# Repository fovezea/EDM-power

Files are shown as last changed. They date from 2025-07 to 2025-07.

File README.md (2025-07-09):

# EDM Power Control System

A comprehensive ESP32-based EDM (Electrical Discharge Machining) power supply and control system with real-time web interface, PID control, and persistent settings management.

## 🎯 **Project Goals**

- **Real-time EDM Control**: Precise electrode positioning with PID feedback
- **Web Interface**: Modern responsive web UI for monitoring and control
- **Persistent Settings**: NVS-based settings storage with web configuration
- **Safety Features**: Limit switch protection and emergency stops
- **Modular Design**: Clean separation of concerns for maintainability

### **EDM Philosophy & Approach**

EDM machines, due to the spark (plasma) not being fully understood and the lack of a mathematical model that fits the way we try to simplify the equations, are still esoteric in nature and there is still a lot of empirical approach. Combined with the variety of materials and electrodes, this creates a complex situation.

As far as I understand, there is not a single type of power source in an industrial machine, but rather a combination of several sources depending on the operation. The target is to have flexibility to control the same hardware to do as much as possible.

There is a lot of documentation and publications out there, but there is still a gap between implementation and theoretical approach.

## ✨ **Current Features**

### 🔧 **Core EDM Functionality**
- **Stepper Motor Control**: Smooth acceleration/deceleration with RMT peripheral
- **PID Control Loop**: Configurable proportional, integral, and derivative gains
- **Gap Voltage Monitoring**: Real-time ADC sampling with configurable blanking delay
- **PWM Power Generation**: Half-bridge IGBT control with dead time protection
- **Safety Interlocks**: Limit switch protection and emergency stop functionality

### 🌐 **Web Interface & Connectivity**
- **WiFi Station Mode**: Automatic connection with retry logic
- **Real-time Web UI**: Modern responsive interface accessible via browser
- **WebSocket Communication**: Live status updates and command control
- **Cross-platform**: Works on desktop, tablet, and mobile devices

### ⚙️ **Settings Management**
- **Persistent Storage**: NVS-based settings that survive power cycles
- **Web Configuration**: Real-time parameter adjustment via web interface
- **Default Values**: Automatic fallback to sensible defaults
- **Settings Reset**: One-click restore to factory defaults

### 📊 **Configurable Parameters**
- **PWM Duty Cycle**: 1-99% with real-time adjustment
- **ADC Blanking Delay**: 10-200 ticks for noise filtering
- **PID Parameters**: 
  - Kp (Proportional): 0.000-1.000
  - Ki (Integral): 0.000-1.000  
  - Kd (Derivative): 0.000-1.000
  - Setpoint: 0-4095 ADC value
- **Speed Settings**: Jog and cut speeds in mm/s

## 🚀 **Getting Started**

### **Prerequisites**
- ESP-IDF v5.4.1 or later
- ESP32 development board
- DRV8825 stepper motor driver
- 4-wire stepper motor
- Half-bridge IGBT module
- Limit switch and control buttons

### **Hardware Connections**

```
+---------------------------+             +--------------------+      +--------------+
|          ESP32 Board      |             |       DRV8825      |      |    4-wire    |
|                       GND +-------------+ GND                |      |     Step     |
|                           |             |                    |      |     Motor    |
|                       3V3 +-------------+ VDD             A+ +------+ A+           |
|                           |             |                    |      |              |
|       GPIO 2 (DIR)        +------------>+ DIR             A- +------+ A-           |
|                           |             |                    |      |              |
|       GPIO 4 (STEP)       +------------>+ STEP            B- +------+ B-           |
|                           |             |                    |      |              |
|                           |      3V3----+ nSLEEP          B+ +------+ B+           |
|                           |             |                    |      +--------------+
|                           |      3V3----+ nRST            VM +-------------------+
|                           |             |                    |                   |
|                           |  3V3|GND----+ M2             GND +----------+        |
|                           |             |                    |          |        |
|                           |  3V3|GND----+ M1                 |          |        |
|                           |             |                    |          |        |
|                           |  3V3|GND----+ M0                 |      +---+--------+-----+
|                           |             |                    |      |  GND     +12V    |
|       GPIO 0 (ENABLE)     +------------>+ nEN                |      |   POWER SUPPLY   |
+---------------------------+             +--------------------+      +------------------+

PWM Outputs:
- GPIO 16 (PWM0A) -> IGBT High Side
- GPIO 17 (PWM0B) -> IGBT Low Side
- GPIO 18 (CAP)   -> External Signal Capture

Control Inputs:
- GPIO 12 (JOG_UP)     -> Jog Up Button
- GPIO 13 (JOG_DOWN)   -> Jog Down Button  
- GPIO 14 (LIMIT)      -> Limit Switch
- GPIO 15 (START_CUT)  -> Start/Stop Button

ADC Input:
- GPIO 6 (ADC_CH6)     -> Gap Voltage Sensing
```

### **Build and Flash**

1. **Configure WiFi** (optional):
   ```bash
   idf.py menuconfig
   # Navigate to: Component config -> WiFi Configuration
   # Set your WiFi credentials
   ```

2. **Build and flash**:
   ```bash
   idf.py build
   idf.py -p [PORT] flash monitor
   ```

3. **Access Web Interface**:
   - Connect to the ESP32's WiFi network (if in AP mode)
   - Or connect to your WiFi and note the IP address from serial output
   - Open browser and navigate to: `http://[ESP32_IP_ADDRESS]`

## 📁 **Project Structure**

```
main/
├── main.c                 # Core application logic and task management
├── MCPWM_task.c          # PWM generation and PID control loop
├── ADC.c                 # ADC sampling and gap voltage capture
├── stepper_motor_encoder.c # RMT-based stepper motor control
├── wifi_connect.c        # WiFi station mode with auto-reconnect
├── web_server.c          # HTTP server and WebSocket communication
├── settings.c            # NVS-based persistent settings management
├── web_server.h          # Web interface definitions
├── wifi_connect.h        # WiFi connection interface
└── settings.h            # Settings management interface
```

## 🎛️ **Web Interface Features**

### **Real-time Monitoring**
- **Gap Voltage**: Live ADC readings with voltage conversion
- **PWM Duty Cycle**: Current duty cycle percentage
- **System Status**: Cutting state, limit switch, WiFi connection
- **Motor Position**: Current step position and speeds
- **PID Parameters**: Current Kp, Ki, Kd, and setpoint values

### **Control Panel**
- **EDM Control**: Start/Stop cutting operations
- **Manual Jogging**: Up/Down movement with safety limits
- **Home Position**: Return to reference position
- **Settings Reset**: Restore factory defaults

### **Parameter Configuration**
- **Duty Cycle Slider**: 1-99% PWM control
- **ADC Blanking Delay**: 10-200 ticks for noise filtering
- **PID Tuning**: Real-time adjustment of control parameters
- **Setpoint Control**: Target ADC value for gap control

## 🔧 **Technical Details**

### **RMT-Based Stepper Control**
One RMT TX channel can use different encoders in sequence, which is useful to generate waveforms that have multiple stages.

To smoothly drive a stepper motor, there are three phases: **Acceleration**, **Uniform**, and **Deceleration**. The code implements two encoders so that the RMT channel can generate waveforms with different characteristics:

* `curve_encoder` encodes the **Acceleration** and **Deceleration** phases
* `uniform_encoder` encodes the **Uniform** phase

### **PID Control Loop**
The system uses a PID controller to maintain optimal gap voltage:
- **Proportional (Kp)**: Responds to current error
- **Integral (Ki)**: Eliminates steady-state error
- **Derivative (Kd)**: Reduces overshoot and oscillations
- **Setpoint**: Target ADC value for gap control

### **Control Logic & Safety Features**

The main control loop implements comprehensive safety and operational logic:

- **Jogging Control**: Manual movement only allowed if limit switch is ON (not triggered)
- **EDM Cutting**: Only runs if not jogging, limit switch is ON, and start button is ON
- **Safety Inhibition**: If limit switch is OFF, all movement is inhibited (including jogging and EDM control)
- **Range Validation**: All parameters validated before application
- **Fault Logging**: Comprehensive error reporting

The loop now fully supports the new safety and control logic with clear separation of jog and cut operations.

### **Safety Features**
- **Limit Switch Protection**: Inhibits all movement when triggered
- **Emergency Stop**: Immediate halt of all operations
- **Range Validation**: All parameters validated before application
- **Fault Logging**: Comprehensive error reporting

### **Performance Characteristics**
- **Update Rate**: 50Hz PID control loop
- **ADC Resolution**: 12-bit (0-4095)
- **PWM Frequency**: 20kHz with configurable duty cycle
- **Stepper Resolution**: 200 steps/revolution
- **WebSocket Latency**: <100ms for real-time control

## 🛠️ **Configuration**

### **WiFi Setup**
Edit `main/wifi_connect.c` to configure your WiFi credentials:
```c
#define WIFI_SSID "your_wifi_ssid"
#define WIFI_PASS "your_wifi_password"
```

### **GPIO Configuration**
Modify GPIO assignments in `main/main.c`:
```c
#define STEP_MOTOR_GPIO_EN       0
#define STEP_MOTOR_GPIO_DIR      2
#define STEP_MOTOR_GPIO_STEP     4
#define JOG_UP_GPIO   12
#define JOG_DOWN_GPIO 13
#define LIMIT_SWITCH_GPIO 14
#define START_CUT_GPIO    15
```

### **Default Settings**
Adjust default values in `main/settings.h`:
```c
#define DEFAULT_DUTY_PERCENT 40
#define DEFAULT_ADC_BLANKING_DELAY 1
#define DEFAULT_PID_KP 0.05f
#define DEFAULT_PID_KI 0.01f
#define DEFAULT_PID_KD 0.0f
#define DEFAULT_PID_SETPOINT 1500
```

## 📈 **Future Enhancements**

- **External ADC Support**: Higher precision voltage measurement
- **Multi-axis Control**: Support for X, Y, Z positioning
- **G-code Interpreter**: CNC-style programming interface
- **Data Logging**: Historical performance tracking
- **Advanced PID Tuning**: Auto-tuning algorithms
- **Material Database**: Pre-configured settings for different materials

## 🤝 **Contributing**

This project is actively developed for EDM applications. Contributions are welcome for:
- Hardware improvements
- Control algorithm enhancements
- Web interface features
- Documentation updates

## 📄 **License**

This project is open source. See LICENSE file for details.

## 📸 **Project Hardware Setup**

Below is a photo of the current hardware setup:

Project Hardware Setup

---

**Note**: This hardware schematic is writen in Kicad 9 but so far is just  power stage control without the reset of the generator. It will be added soon
**Note**: This system is designed for educational and experimental use. Always follow proper safety procedures when working with high-voltage EDM systems.

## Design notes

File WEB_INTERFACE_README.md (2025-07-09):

# EDM Power Control - Web Interface

## 🚀 Overview

Your EDM system now includes a complete web-based control interface that allows you to monitor and control your EDM machine remotely via WiFi.

## 📋 Features

### Real-time Monitoring
- **PWM Duty Cycle** - Live display and control (1-99%)
- **Gap Voltage** - Real-time ADC readings with voltage conversion
- **System Status** - Cutting status, limit switch, WiFi connection
- **Speed Parameters** - Jog speed, cut speed, stepper position
- **Uptime** - System running time

### Remote Control
- **Start/Stop EDM Cutting** - Remote control of cutting process
- **Jog Controls** - Up/down movement commands
- **Home Position** - Return to reference position
- **Duty Cycle Adjustment** - Real-time PWM control via slider

### Live Charting
- **Gap Voltage Chart** - Real-time plotting of gap voltage over time
- **Auto-scaling** - Adapts to voltage range
- **Data History** - Last 50 data points displayed

## 🔧 Setup Instructions

### 1. Configure WiFi
Edit `main/wifi_connect.h` and set your WiFi credentials:
```c
#define WIFI_SSID "YOUR_WIFI_SSID"
#define WIFI_PASS "YOUR_WIFI_PASSWORD"
```

### 2. Build and Flash
```bash
idf.py build
idf.py flash monitor
```

### 3. Access the Web Interface
1. Connect your device to the same WiFi network as your ESP32
2. Look for the ESP32's IP address in the serial monitor output
3. Open your web browser and navigate to: `http://[ESP32_IP_ADDRESS]`

## 🎮 How to Use

### Web Interface Controls

#### **Status Cards**
- **PWM Duty Cycle**: Shows current duty cycle and provides a slider for adjustment
- **Gap Voltage**: Displays real-time gap voltage in millivolts and raw ADC value
- **System Status**: Shows cutting status, limit switch state, and WiFi connection
- **Speeds**: Displays jog speed, cut speed, and current stepper position

#### **Control Panel**
- **Start EDM Cut**: Begin the EDM cutting process
- **Stop EDM Cut**: Stop the EDM cutting process
- **Jog Up**: Move electrode up
- **Jog Down**: Move electrode down
- **Home Position**: Return to home position

#### **Real-time Chart**
- **Gap Voltage Chart**: Live plotting of gap voltage over time
- **Auto-scaling**: Automatically adjusts to show the full voltage range
- **Data History**: Maintains the last 50 data points

### Connection Status
- **Green**: Connected to ESP32 via WebSocket
- **Red**: Disconnected (will auto-reconnect)

## 🔌 Technical Details

### WebSocket Communication
- **Real-time Updates**: 1-second refresh rate
- **Bidirectional**: Commands from web to ESP32, status from ESP32 to web
- **Multiple Clients**: Support for up to 4 simultaneous connections
- **Auto-reconnection**: Client automatically reconnects if connection lost

### Integration with EDM System
- **Command Queue**: Thread-safe communication between web and main tasks
- **Status Synchronization**: Real-time updates from existing EDM code
- **Error Handling**: Graceful fallback if WiFi/web server fails
- **ESP-IDF v5.4.1 Compatible**: Uses latest APIs

## 📱 Mobile Support
The web interface is fully responsive and works on:
- Desktop computers
- Tablets
- Smartphones

## 🛠️ Troubleshooting

### WiFi Connection Issues
1. Check WiFi credentials in `wifi_connect.h`
2. Ensure ESP32 is within WiFi range
3. Check serial monitor for connection status

### Web Interface Not Loading
1. Verify ESP32 IP address in serial monitor
2. Check if ESP32 and device are on same network
3. Try refreshing the browser page

### Commands Not Working
1. Check WebSocket connection status (should be green)
2. Verify ESP32 is not in a critical state (limit switch triggered)
3. Check serial monitor for error messages

## 🔒 Security Notes
- The web interface is designed for local network use
- No authentication is implemented (add if needed for production)
- Consider using HTTPS for production environments

## 📊 Performance
- **Update Rate**: 1 second for status updates
- **Chart Data**: 50 data points maintained
- **Memory Usage**: ~8KB for web server task
- **CPU Usage**: Minimal impact on EDM performance

## 🎯 Next Steps
Consider adding these features:
- **User Authentication**: Login system for security
- **Data Logging**: Save cutting data to SD card
- **Email Alerts**: Notifications for system events
- **Advanced Charts**: Multiple parameter plotting
- **Recipe Management**: Save and load cutting parameters

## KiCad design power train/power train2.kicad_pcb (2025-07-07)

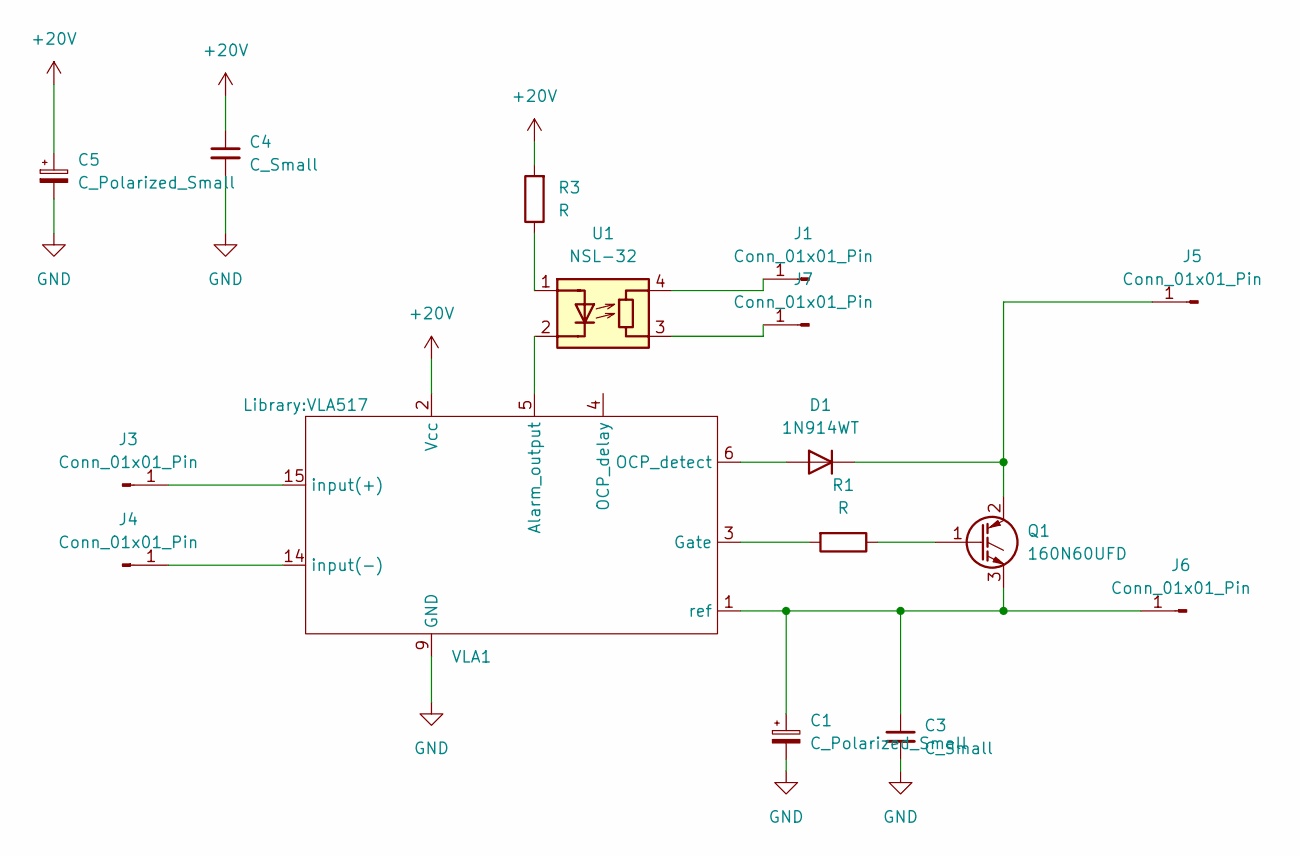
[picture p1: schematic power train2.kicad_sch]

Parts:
C1, C5: C_Polarized_Small; CP_Radial_D8.0mm_P3.50mm
C3, C4: C_Small; C_Axial_L5.1mm_D3.1mm_P7.50mm_Horizontal
D1: 1N914WT; D_SOD-523
J1, J3, J4, J5, J6, J7: Conn_01x01_Pin; TestPoint_THTPad_1.0x1.0mm_Drill0.5mm
Q1: 160N60UFD; TO-264-3_Vertical
R1, R3: R; R_Axial_DIN0309_L9.0mm_D3.2mm_P12.70mm_Horizontal
U1: NSL-32; Luna_NSL-32
VLA1: VLA517

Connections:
+20V: C4.1, C5.1, R3.2, VLA1.2 (Vcc)
GND: C1.2, C3.2, C4.2, C5.2, VLA1.9 (GND)
unnamed: D1.2 (A), VLA1.6 (OCP_detect)
unnamed: D1.1 (K), J5.1, Q1.2 (C)
unnamed: J1.1, U1.4 (R)
unnamed: J3.1, VLA1.15 (input(+))
unnamed: J4.1, VLA1.14 (input(-))
unnamed: C1.1, C3.1, J6.1, Q1.3 (E), VLA1.1 (ref)
unnamed: J7.1, U1.3 (R)
unnamed: Q1.1 (G), R1.1
unnamed: R3.1, U1.1 (A)
unnamed: U1.2 (K), VLA1.5 (Alarm_output)
unnamed: R1.2, VLA1.3 (Gate)

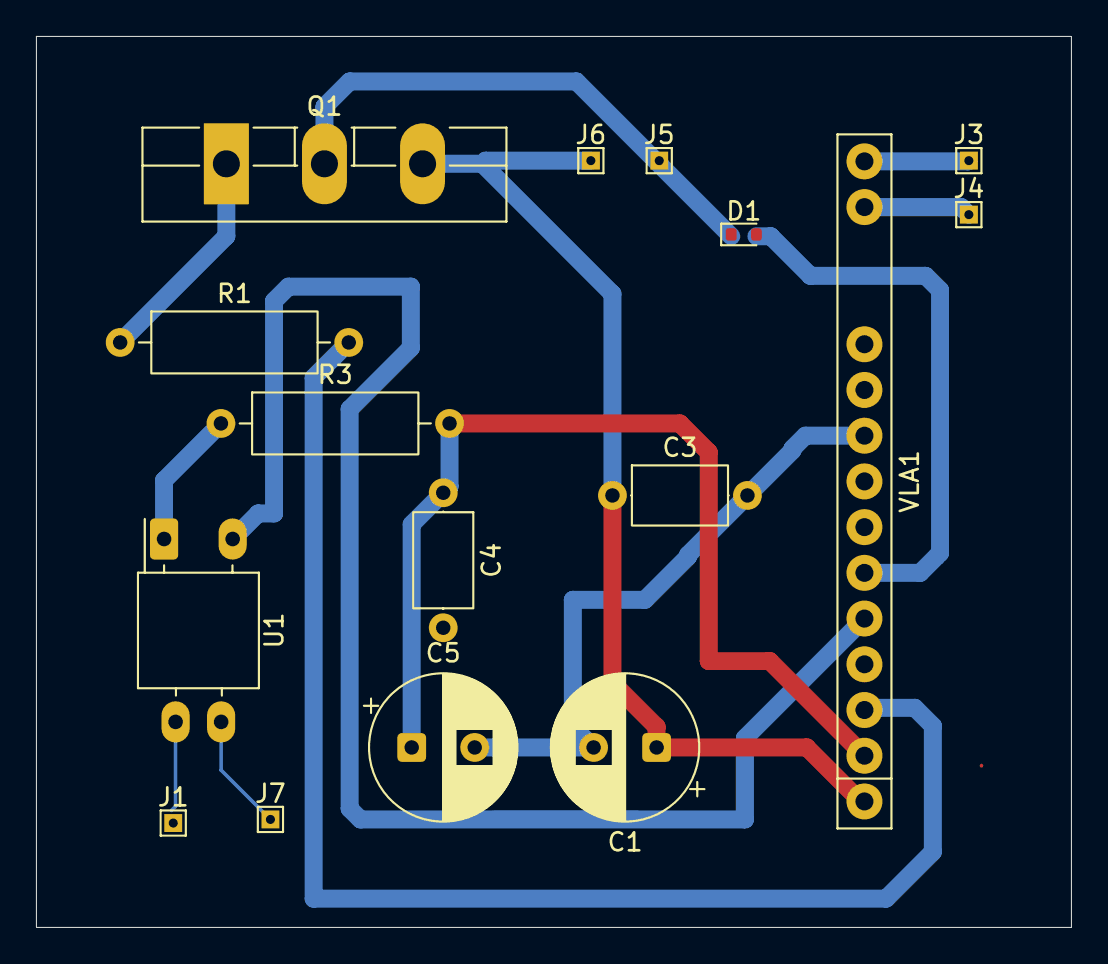
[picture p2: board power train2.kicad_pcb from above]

Board: 2 copper layers, 57.5 x 49.5 mm, 16 parts (0 on the bottom side), 13 nets.

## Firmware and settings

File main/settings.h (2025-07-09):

/*
 * Settings Management for EDM Power Project
 * Uses NVS (Non-Volatile Storage) for persistent settings
 */

#pragma once

#include "esp_err.h"
#include "nvs_flash.h"
#include "nvs.h"

#ifdef __cplusplus
extern "C" {
#endif

// Settings structure
typedef struct {
    int duty_percent;           // PWM duty cycle (1-99)
    int adc_blanking_delay;     // ADC lead edge blanking delay (10-200 ticks)
    float jog_speed;            // Jog speed in mm/s
    float cut_speed;            // Cut speed in mm/s
    // PID control parameters
    float pid_kp;               // Proportional gain
    float pid_ki;               // Integral gain
    float pid_kd;               // Derivative gain
    int pid_setpoint;           // Target ADC value
    bool pid_control_enabled;   // Whether PID control is enabled
    // Add more settings as needed
} edm_settings_t;

// Function declarations
esp_err_t settings_init(void);
esp_err_t settings_load(edm_settings_t *settings);
esp_err_t settings_save(const edm_settings_t *settings);
esp_err_t settings_reset_to_defaults(void);
void settings_deinit(void);

// Default settings
#define DEFAULT_DUTY_PERCENT 40
#define DEFAULT_ADC_BLANKING_DELAY 10
#define DEFAULT_JOG_SPEED 1.0f
#define DEFAULT_CUT_SPEED 0.1f
// PID default values
#define DEFAULT_PID_KP 0.05f
#define DEFAULT_PID_KI 0.01f
#define DEFAULT_PID_KD 0.0f
#define DEFAULT_PID_SETPOINT 1500
#define DEFAULT_PID_CONTROL_ENABLED false

#ifdef __cplusplus
}
#endif 

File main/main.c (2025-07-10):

/*
 * SPDX-FileCopyrightText: 2021-2022 Espressif Systems (Shanghai) CO LTD
 *
 * SPDX-License-Identifier: Unlicense OR CC0-1.0
 */

#include "freertos/FreeRTOS.h"
#include "freertos/task.h"
#include "driver/rmt_tx.h"
#include "driver/gpio.h"
#include "esp_log.h"
#include "stepper_motor_encoder.h"
#include "freertos/semphr.h"
#include "nvs_flash.h"

#include "esp_adc/adc_cali.h"
#include "esp_adc/adc_cali_scheme.h"
#include "esp_adc/adc_oneshot.h"

// Web server and WiFi includes
#include "wifi_connect.h"
#include "web_server.h"
#include "settings.h"
#include "freertos/queue.h"
#include <string.h>

///////////////////////////////Change the following configurations according to your board//////////////////////////////
#define STEP_MOTOR_GPIO_EN       0
#define STEP_MOTOR_GPIO_DIR      2
#define STEP_MOTOR_GPIO_STEP     4
#define STEP_MOTOR_ENABLE_LEVEL  0 // DRV8825 is enabled on low level
#define STEP_MOTOR_SPIN_DIR_CLOCKWISE 0
#define STEP_MOTOR_SPIN_DIR_COUNTERCLOCKWISE !STEP_MOTOR_SPIN_DIR_CLOCKWISE
#define HYSTERESIS_WIDTH 100 // ADC value dead zone width
//buttons for jogging
#define JOG_UP_GPIO   12  // Choose your GPIO numbers
#define JOG_DOWN_GPIO 13
#define LIMIT_SWITCH_GPIO 14
#define START_CUT_GPIO    15

#define STEP_MOTOR_RESOLUTION_HZ 1000000 // 1MHz resolution

// Speed and leadscrew pitch settings
double jog_speed_mm_per_s = 1; // Speed in mm/s, can be set from elsewhere
double cut_speed_mm_per_s = 0.1; // Speed in mm/s, can be set from elsewhere
double leadscrew_pitch_mm = 4.0; // Leadscrew pitch in mm/rev
double steps_per_rev = 2000; // Pulses per revolution (e.g., 200 for 1.8 degree stepper)

static const char *TAG = "main";

#include "freertos/queue.h"
QueueHandle_t pwm_adc_queue = NULL;

// Only extern variables that are defined in other files and actually used in main.c
extern volatile uint32_t last_capture_ticks;
extern volatile int adc_value_on_capture;
extern SemaphoreHandle_t capture_semaphore;

// Extern declaration for adc_on_capture_task (defined in ADC.c)
extern void adc_on_capture_task(void *pvParameters);
extern void mcpwm_halfbridge_task(void *pvParameters);
extern void adc_oneshot_init(void); // Add extern for ADC init

// Web server integration variables
static volatile bool edm_cutting_enabled = false;
static volatile bool jog_up_requested = false;
static volatile bool jog_down_requested = false;
static volatile bool home_position_requested = false;
static volatile bool web_control_active = false; // Default: physical buttons in control
QueueHandle_t command_queue = NULL;

// Command structure for web interface
typedef struct {
    char command[32];
    int value;
} web_command_t;

// Web server task function declaration
void web_server_task(void *pvParameters);
extern esp_err_t web_server_init(void);

// Local static/global variables (defined in this file and actually used)
static rmt_channel_handle_t motor_chan;
static rmt_encoder_handle_t accel_motor_encoder;
static rmt_encoder_handle_t uniform_motor_encoder;
static rmt_encoder_handle_t decel_motor_encoder;
static rmt_encoder_handle_t cut_motor_encoder = NULL;
// Pre-configured cut encoders for different speeds
static rmt_encoder_handle_t cut_encoder_slow = NULL;    // 0.01-0.1 mm/s
static rmt_encoder_handle_t cut_encoder_medium = NULL;  // 0.1-0.5 mm/s  
static rmt_encoder_handle_t cut_encoder_fast = NULL;    // 0.5-1.0 mm/s

// Web server integration functions
bool get_edm_cutting_status(void) {
    return edm_cutting_enabled;
}

bool get_jog_up_requested(void) {
    bool requested = jog_up_requested;
    jog_up_requested = false; // Clear the request
    return requested;
}

bool get_jog_down_requested(void) {
    bool requested = jog_down_requested;
    jog_down_requested = false; // Clear the request
    return requested;
}

bool get_home_position_requested(void) {
    bool requested = home_position_requested;
    home_position_requested = false; // Clear the request
    return requested;
}

bool get_web_control_active(void) {
    return web_control_active;
}

void set_web_control_active(bool active) {
    if (active && !web_control_active) {
        // When switching to web control, inherit the current physical cutting state
        int physical_start_cut = gpio_get_level(START_CUT_GPIO);
        edm_cutting_enabled = (physical_start_cut == 1);
        ESP_LOGI(TAG, "Taking web control - inherited cutting state: %s", 
                 edm_cutting_enabled ? "CUTTING" : "STOPPED");
    }
    
    web_control_active = active;
    ESP_LOGI(TAG, "Control switched to: %s", active ? "WEB" : "PHYSICAL");
}

// Function to select appropriate pre-configured encoder based on cut speed
void update_cut_motor_encoder(void) {
    ESP_LOGI(TAG, "=== Selecting cut motor encoder ===");
    ESP_LOGI(TAG, "Current cut_speed_mm_per_s: %.3f", cut_speed_mm_per_s);
    
    rmt_encoder_handle_t old_encoder = cut_motor_encoder;
    
    // Select encoder based on speed range
    if (cut_speed_mm_per_s <= 0.1) {
        cut_motor_encoder = cut_encoder_slow;
        ESP_LOGI(TAG, "Selected SLOW encoder for %.3f mm/s", cut_speed_mm_per_s);
    } else if (cut_speed_mm_per_s <= 0.5) {
        cut_motor_encoder = cut_encoder_medium;
        ESP_LOGI(TAG, "Selected MEDIUM encoder for %.3f mm/s", cut_speed_mm_per_s);
    } else {
        cut_motor_encoder = cut_encoder_fast;
        ESP_LOGI(TAG, "Selected FAST encoder for %.3f mm/s", cut_speed_mm_per_s);
    }
    
    if (cut_motor_encoder == NULL) {
        ESP_LOGE(TAG, "✗ Selected encoder is NULL! Falling back to uniform encoder");
        cut_motor_encoder = uniform_motor_encoder;
    } else {
        ESP_LOGI(TAG, "✓ Cut encoder selected: old=%p, new=%p", old_encoder, cut_motor_encoder);
    }
    ESP_LOGI(TAG, "=== Encoder selection complete ===");
}

// Web server integration task
void web_integration_task(void *pvParameters)
{
    ESP_LOGI(TAG, "Web integration task started");
    
    // Create command queue
    command_queue = xQueueCreate(10, sizeof(web_command_t));
    
    // Initialize WiFi first
    esp_err_t wifi_ret = wifi_init_sta();
    if (wifi_ret != ESP_OK) {
        ESP_LOGE(TAG, "Failed to connect to WiFi, web interface will not be available");
    } else {
        ESP_LOGI(TAG, "WiFi connected successfully");
        
        // Wait a bit for WiFi to stabilize
        vTaskDelay(pdMS_TO_TICKS(2000));
        
        // Initialize web server
        esp_err_t web_ret = web_server_start();
        if (web_ret != ESP_OK) {
            ESP_LOGE(TAG, "Failed to start web server, retrying...");
            // Wait and retry once
            vTaskDelay(pdMS_TO_TICKS(5000));
            web_ret = web_server_start();
            if (web_ret != ESP_OK) {
                ESP_LOGE(TAG, "Web server start failed after retry, continuing without web interface");
            } else {
                ESP_LOGI(TAG, "Web server started successfully after retry");
                xTaskCreate(web_server_task, "web_server_task", 8192, NULL, 4, NULL);
                ESP_LOGI(TAG, "Access the EDM control interface at: http://[ESP32_IP_ADDRESS]");
            }
        } else {
            ESP_LOGI(TAG, "Web server started successfully");
            xTaskCreate(web_server_task, "web_server_task", 8192, NULL, 4, NULL);
            ESP_LOGI(TAG, "Access the EDM control interface at: http://[ESP32_IP_ADDRESS]");
        }
    }
    
    // Main integration loop
    while (1) {
        // Process commands from web interface
        web_command_t cmd;
        if (xQueueReceive(command_queue, &cmd, pdMS_TO_TICKS(100)) == pdTRUE) {
            // ESP_LOGI(TAG, "Processing web command: %s, value: %d", cmd.command, cmd.value);
            
            if (strcmp(cmd.command, "set_duty") == 0) {
                duty_percent = cmd.value;
                ESP_LOGI(TAG, "Duty cycle set to %d%% via web interface", cmd.value);
            } else if (strcmp(cmd.command, "start_cut") == 0) {
                edm_cutting_enabled = true;
                ESP_LOGI(TAG, "EDM cutting started via web interface");
            } else if (strcmp(cmd.command, "stop_cut") == 0) {
                edm_cutting_enabled = false;
                ESP_LOGI(TAG, "EDM cutting stopped via web interface");
            } else if (strcmp(cmd.command, "jog_up") == 0) {
                jog_up_requested = true;
                ESP_LOGI(TAG, "Jog up requested via web interface");
            } else if (strcmp(cmd.command, "jog_down") == 0) {
                jog_down_requested = true;
                ESP_LOGI(TAG, "Jog down requested via web interface");
            } else if (strcmp(cmd.command, "home_position") == 0) {
                home_position_requested = true;
                ESP_LOGI(TAG, "Home position requested via web interface");
            } else if (strcmp(cmd.command, "web_control") == 0) {
                set_web_control_active(cmd.value != 0);
                ESP_LOGI(TAG, "Web control %s via web interface", cmd.value != 0 ? "enabled" : "disabled");
            } else if (strcmp(cmd.command, "set_cut_speed") == 0) {
                // cut_speed_mm_per_s is already updated by web_server.c
                // Always update encoder immediately - it's safe between RMT transmissions
                ESP_LOGI(TAG, "Cut speed change - updating encoder immediately");
                update_cut_motor_encoder();
                ESP_LOGI(TAG, "Cut speed updated to %.3f mm/s via web interface", cut_speed_mm_per_s);
            } else if (strcmp(cmd.command, "set_jog_speed") == 0) {
                // jog_speed_mm_per_s is already updated by web_server.c
                ESP_LOGI(TAG, "Jog speed updated to %.3f mm/s via web interface", jog_speed_mm_per_s);
            }
        }
        
        vTaskDelay(pdMS_TO_TICKS(100)); // Check every 100ms
    }
}

// The task function
void stepper_task(void *pvParameters)
{
 
    ////////////////////////
    // Configure EN + DIR as outputs
    // ESP_LOGI(TAG, "Initialize EN + DIR GPIO");
    gpio_config_t en_dir_gpio_config = {
        .mode = GPIO_MODE_OUTPUT,
        .intr_type = GPIO_INTR_DISABLE,
        .pin_bit_mask = 1ULL << STEP_MOTOR_GPIO_DIR | 1ULL << STEP_MOTOR_GPIO_EN,
    };
    ESP_ERROR_CHECK(gpio_config(&en_dir_gpio_config));

    // Configure jog and limit GPIOs
    // ESP_LOGI(TAG, "Initialize jog and limit GPIOs");
    gpio_config_t jog_gpio_config = {
        .mode = GPIO_MODE_INPUT,
        .intr_type = GPIO_INTR_DISABLE,
        .pin_bit_mask = (1ULL << JOG_UP_GPIO) | (1ULL << JOG_DOWN_GPIO),
        .pull_up_en = GPIO_PULLUP_DISABLE,
        .pull_down_en = GPIO_PULLDOWN_ENABLE,
    };
    ESP_ERROR_CHECK(gpio_config(&jog_gpio_config));

    gpio_config_t limit_gpio_config = {
        .mode = GPIO_MODE_INPUT,
        .intr_type = GPIO_INTR_DISABLE,
        .pin_bit_mask = (1ULL << LIMIT_SWITCH_GPIO) | (1ULL << START_CUT_GPIO),
        .pull_up_en = GPIO_PULLUP_ENABLE,
        .pull_down_en = GPIO_PULLDOWN_DISABLE,
    };
    ESP_ERROR_CHECK(gpio_config(&limit_gpio_config));

    //calculate stepper frequency from mm/s
    double jog_freq_hz = stepper_calc_freq_from_speed(jog_speed_mm_per_s, steps_per_rev, leadscrew_pitch_mm);
    // ESP_LOGI(TAG, "Calculated stepper jog frequency: %.2f Hz", jog_freq_hz);
    //calculate cut frequency from mm/s
    double cut_freq_hz = stepper_calc_freq_from_speed(cut_speed_mm_per_s, steps_per_rev, leadscrew_pitch_mm);
    // ESP_LOGI(TAG, "Calculated stepper cut frequency: %.2f Hz", cut_freq_hz);


    // Create RMT TX channel
    // ESP_LOGI(TAG, "Create RMT TX channel");
    //rmt_channel_handle_t motor_chan = NULL;
    rmt_tx_channel_config_t tx_chan_config = {
        .clk_src = RMT_CLK_SRC_DEFAULT, // select clock source
        .gpio_num = STEP_MOTOR_GPIO_STEP,
        .mem_block_symbols = 64,
        .resolution_hz = STEP_MOTOR_RESOLUTION_HZ,
        .trans_queue_depth = 10, // set the number of transactions that can be pending in the background
    };
    ESP_ERROR_CHECK(rmt_new_tx_channel(&tx_chan_config, &motor_chan));

    // ESP_LOGI(TAG, "Set spin direction");
    gpio_set_level(STEP_MOTOR_GPIO_DIR, STEP_MOTOR_SPIN_DIR_CLOCKWISE);
    // ESP_LOGI(TAG, "Enable step motor");
    gpio_set_level(STEP_MOTOR_GPIO_EN, STEP_MOTOR_ENABLE_LEVEL);

    // ESP_LOGI(TAG, "Create motor encoders");
    stepper_motor_curve_encoder_config_t accel_encoder_config = {0};
    accel_encoder_config.resolution = STEP_MOTOR_RESOLUTION_HZ;
    accel_encoder_config.sample_points = 1000;
    accel_encoder_config.start_freq_hz = 500;
    accel_encoder_config.end_freq_hz = 1500;
    ESP_ERROR_CHECK(rmt_new_stepper_motor_curve_encoder(&accel_encoder_config, &accel_motor_encoder));
    if (accel_motor_encoder == NULL) {
        ESP_LOGE(TAG, "Failed to create accel_motor_encoder");
        return;
    }

    // Jog encoder: use curve encoder for configurable jog speed
    static rmt_encoder_handle_t jog_motor_encoder = NULL;
    stepper_motor_curve_encoder_config_t jog_curve_config = {0};
    jog_curve_config.resolution = STEP_MOTOR_RESOLUTION_HZ;
    jog_curve_config.sample_points = 2; // For constant speed, must be <= |start_freq_hz - end_freq_hz|
    jog_curve_config.start_freq_hz = 1500; // Increased jog speed (Hz)
    jog_curve_config.end_freq_hz = 1498;   // Must not be equal to start_freq_hz, and difference >= sample_points
    ESP_ERROR_CHECK(rmt_new_stepper_motor_curve_encoder(&jog_curve_config, &jog_motor_encoder));
    if (jog_motor_encoder == NULL) {
        ESP_LOGE(TAG, "Failed to create jog_motor_encoder");
        return;
    }

    stepper_motor_uniform_encoder_config_t uniform_encoder_config = {0};
    uniform_encoder_config.resolution = STEP_MOTOR_RESOLUTION_HZ;
    ESP_ERROR_CHECK(rmt_new_stepper_motor_uniform_encoder(&uniform_encoder_config, &uniform_motor_encoder));
    if (uniform_motor_encoder == NULL) {
        ESP_LOGE(TAG, "Failed to create uniform_motor_encoder");
        return;
    }

    stepper_motor_curve_encoder_config_t decel_encoder_config = {0};
    decel_encoder_config.resolution = STEP_MOTOR_RESOLUTION_HZ;
    decel_encoder_config.sample_points = 1000;
    decel_encoder_config.start_freq_hz = 1500;
    decel_encoder_config.end_freq_hz = 500;
    ESP_ERROR_CHECK(rmt_new_stepper_motor_curve_encoder(&decel_encoder_config, &decel_motor_encoder));
    if (decel_motor_encoder == NULL) {
        ESP_LOGE(TAG, "Failed to create decel_motor_encoder");
        return;
    }

    // Create pre-configured cut motor encoders for different speed ranges
    ESP_LOGI(TAG, "Creating pre-configured cut encoders");
    
    // Calculate actual frequencies based on current parameters
    // Using: freq = (speed_mm_per_s * steps_per_rev) / leadscrew_pitch_mm
    uint32_t slow_freq = (uint32_t)((0.05 * steps_per_rev) / leadscrew_pitch_mm);   // 0.05 mm/s = 25 Hz
    uint32_t medium_freq = (uint32_t)((0.2 * steps_per_rev) / leadscrew_pitch_mm); // 0.2 mm/s = 100 Hz  
    uint32_t fast_freq = (uint32_t)((1.0 * steps_per_rev) / leadscrew_pitch_mm);   // 1.0 mm/s = 500 Hz
    
    // Ensure minimum frequency to prevent extremely long step pulses
    // Use higher minimum to ensure reasonable step pulse timing even at very low speeds
    if (slow_freq < 100) slow_freq = 100;      // Minimum 100Hz = 5ms step period
    if (medium_freq < 100) medium_freq = 100;
    if (fast_freq < 100) fast_freq = 100;
    
    ESP_LOGI(TAG, "Calculated encoder frequencies: slow=%lu Hz, medium=%lu Hz, fast=%lu Hz", 
             (unsigned long)slow_freq, (unsigned long)medium_freq, (unsigned long)fast_freq);
    
    // Slow encoder: for 0.01-0.1 mm/s range
    stepper_motor_curve_encoder_config_t slow_config = {0};
    slow_config.resolution = STEP_MOTOR_RESOLUTION_HZ;
    slow_config.sample_points = 2;
    slow_config.start_freq_hz = slow_freq;
    slow_config.end_freq_hz = slow_freq - 1;
    ESP_ERROR_CHECK(rmt_new_stepper_motor_curve_encoder(&slow_config, &cut_encoder_slow));
    ESP_LOGI(TAG, "Slow cut encoder created: %p (%lu Hz)", cut_encoder_slow, (unsigned long)slow_freq);
    
    // Medium encoder: for 0.1-0.5 mm/s range
    stepper_motor_curve_encoder_config_t medium_config = {0};
    medium_config.resolution = STEP_MOTOR_RESOLUTION_HZ;
    medium_config.sample_points = 2;
    medium_config.start_freq_hz = medium_freq;
    medium_config.end_freq_hz = medium_freq - 1;
    ESP_ERROR_CHECK(rmt_new_stepper_motor_curve_encoder(&medium_config, &cut_encoder_medium));
    ESP_LOGI(TAG, "Medium cut encoder created: %p (%lu Hz)", cut_encoder_medium, (unsigned long)medium_freq);
    
    // Fast encoder: for 0.5-1.0 mm/s range
    stepper_motor_curve_encoder_config_t fast_config = {0};
    fast_config.resolution = STEP_MOTOR_RESOLUTION_HZ;
    fast_config.sample_points = 2;
    fast_config.start_freq_hz = fast_freq;
    fast_config.end_freq_hz = fast_freq - 1;
    ESP_ERROR_CHECK(rmt_new_stepper_motor_curve_encoder(&fast_config, &cut_encoder_fast));
    ESP_LOGI(TAG, "Fast cut encoder created: %p (%lu Hz)", cut_encoder_fast, (unsigned long)fast_freq);
    
    // Select initial cut motor encoder
    update_cut_motor_encoder();

    // ESP_LOGI(TAG, "Enable RMT channel");
    // Debug: print motor_chan handle before enabling
    // ESP_LOGI(TAG, "motor_chan handle: %p", motor_chan);
    esp_err_t err = rmt_enable(motor_chan);
    if (err != ESP_OK) {
        ESP_LOGE(TAG, "Failed to enable RMT channel: %s", esp_err_to_name(err));
        return;
    }
    // Variable declarations moved to function scope
    extern volatile uint32_t last_capture_ticks;
    extern volatile int adc_value_on_capture;
    const int LOW_VOLTAGE = 500;            // adjust based on your ADC scaling
    const int HIGH_VOLTAGE = 2000;          // adjust based on your ADC scaling

    // ESP_LOGI(TAG, "RMT channel enabled, entering main loop");
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
void app_main(void)
{
    pwm_adc_queue = xQueueCreate(1, sizeof(int));
    
    // Initialize NVS
    esp_err_t ret = nvs_flash_init();
    if (ret == ESP_ERR_NVS_NO_FREE_PAGES || ret == ESP_ERR_NVS_NEW_VERSION_FOUND) {
        ESP_ERROR_CHECK(nvs_flash_erase());
        ret = nvs_flash_init();
    }
    ESP_ERROR_CHECK(ret);
    ESP_LOGI(TAG, "NVS initialized successfully");
    
    // Initialize settings system
    esp_err_t settings_ret = settings_init();
    if (settings_ret != ESP_OK) {
        ESP_LOGE(TAG, "Failed to initialize settings system");
    } else {
        // Load settings and apply to global variables
        edm_settings_t settings;
        if (settings_load(&settings) == ESP_OK) {
            duty_percent = settings.duty_percent;
            adc_blanking_delay_ticks = settings.adc_blanking_delay;
            pid_kp = settings.pid_kp;
            pid_ki = settings.pid_ki;
            pid_kd = settings.pid_kd;
            pid_setpoint = settings.pid_setpoint;
            pid_control_enabled = settings.pid_control_enabled;
            ESP_LOGI(TAG, "Settings loaded: Duty=%d%%, ADC Delay=%d ticks", 
                     settings.duty_percent, settings.adc_blanking_delay);
            ESP_LOGI(TAG, "PID: Kp=%.3f, Ki=%.3f, Kd=%.3f, Setpoint=%d, Enabled=%s",
                     settings.pid_kp, settings.pid_ki, settings.pid_kd, settings.pid_setpoint,
                     settings.pid_control_enabled ? "true" : "false");
        }
    }
    
    // Create the main EDM tasks
    xTaskCreate(stepper_task, "stepper_task", 4096, NULL, 5, NULL);
    ESP_LOGI(TAG, "Stepper motor example started");

    adc_oneshot_init(); // Initialize ADC before starting ADC task
    xTaskCreate(adc_on_capture_task, "adc_on_capture_task", 4096, NULL, 1, NULL); // Very low priority to prevent watchdog timeout

    // Start MCPWM task for power train
    xTaskCreate(mcpwm_halfbridge_task, "mcpwm_halfbridge_task", 4096, NULL, 5, NULL);
    
    // Start web server integration task
    xTaskCreate(web_integration_task, "web_integration_task", 8192, NULL, 2, NULL);
    ESP_LOGI(TAG, "Web integration task started");
    
    // The web_integration_task handles WiFi and web server initialization
    ESP_LOGI(TAG, "WiFi and web server will be started by web_integration_task");
}

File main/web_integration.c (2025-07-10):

/*
 * Web Server Integration for EDM Power Project
 * This file shows how to integrate the web server with your main application
 */

#include "web_server.h"
#include "wifi_connect.h"
#include "esp_log.h"
#include "freertos/FreeRTOS.h"
#include "freertos/task.h"
#include "freertos/queue.h"

static const char *TAG = "web_integration";

// Global variables for EDM status
extern volatile int duty_percent;
extern volatile int adc_value_on_capture;
extern SemaphoreHandle_t capture_semaphore;

// EDM control flags
static volatile bool edm_cutting_enabled = false;
static volatile bool jog_up_requested = false;
static volatile bool jog_down_requested = false;
static volatile bool home_position_requested = false;

// Queue for commands from web interface
static QueueHandle_t command_queue = NULL;

// Command structure
typedef struct {
    char command[32];
    int value;
} web_command_t;

// Web server integration task
void web_integration_task(void *pvParameters)
{
    ESP_LOGI(TAG, "Web integration task started");
    
    // Create command queue
    command_queue = xQueueCreate(10, sizeof(web_command_t));
    
    // Initialize web server
    esp_err_t ret = web_server_start();
    if (ret != ESP_OK) {
        ESP_LOGE(TAG, "Failed to start web server");
        return;
    }
    
    // Create web server task
    xTaskCreate(web_server_task, "web_server_task", 8192, NULL, 4, NULL);
    
    ESP_LOGI(TAG, "Web server started successfully");
    ESP_LOGI(TAG, "Access the EDM control interface at: http://[ESP32_IP_ADDRESS]");
    
    // Main integration loop
    while (1) {
        // Process commands from web interface
        web_command_t cmd;
        if (xQueueReceive(command_queue, &cmd, pdMS_TO_TICKS(100)) == pdTRUE) {
            ESP_LOGI(TAG, "Processing web command: %s, value: %d", cmd.command, cmd.value);
            
            if (strcmp(cmd.command, "set_duty") == 0) {
                duty_percent = cmd.value;
                ESP_LOGI(TAG, "Duty cycle set to %d%% via web interface", cmd.value);
            } else if (strcmp(cmd.command, "start_cut") == 0) {
                edm_cutting_enabled = true;
                ESP_LOGI(TAG, "EDM cutting started via web interface");
            } else if (strcmp(cmd.command, "stop_cut") == 0) {
                edm_cutting_enabled = false;
                ESP_LOGI(TAG, "EDM cutting stopped via web interface");
            } else if (strcmp(cmd.command, "jog_up") == 0) {
                jog_up_requested = true;
                ESP_LOGI(TAG, "Jog up requested via web interface");
            } else if (strcmp(cmd.command, "jog_down") == 0) {
                jog_down_requested = true;
                ESP_LOGI(TAG, "Jog down requested via web interface");
            } else if (strcmp(cmd.command, "home_position") == 0) {
                home_position_requested = true;
                ESP_LOGI(TAG, "Home position requested via web interface");
            }
        }
        
        vTaskDelay(pdMS_TO_TICKS(100)); // Check every 100ms
    }
}

// Function to send commands to the integration task
esp_err_t send_web_command(const char *command, int value) {
    if (command_queue == NULL) {
        return ESP_ERR_INVALID_STATE;
    }
    
    web_command_t cmd;
    strncpy(cmd.command, command, sizeof(cmd.command) - 1);
    cmd.command[sizeof(cmd.command) - 1] = '\0';
    cmd.value = value;
    
    if (xQueueSend(command_queue, &cmd, pdMS_TO_TICKS(100)) == pdTRUE) {
        return ESP_OK;
    } else {
        return ESP_ERR_TIMEOUT;
    }
}

// Getter functions for EDM status
bool get_edm_cutting_status(void) {
    return edm_cutting_enabled;
}

bool get_jog_up_requested(void) {
    bool requested = jog_up_requested;
    jog_up_requested = false; // Clear the request
    return requested;
}

bool get_jog_down_requested(void) {
    bool requested = jog_down_requested;
    jog_down_requested = false; // Clear the request
    return requested;
}

bool get_home_position_requested(void) {
    bool requested = home_position_requested;
    home_position_requested = false; // Clear the request
    return requested;
}

// Example of how to modify your main.c to integrate with the web server:
/*
void app_main(void)
{
    // Your existing initialization code
    pwm_adc_queue = xQueueCreate(1, sizeof(int));
    xTaskCreate(stepper_task, "stepper_task", 4096, NULL, 5, NULL);
    ESP_LOGI(TAG, "Stepper motor example started");

    adc_oneshot_init();
    xTaskCreate(adc_on_capture_task, "adc_on_capture_task", 2048, NULL, 10, NULL);
    xTaskCreate(mcpwm_halfbridge_task, "mcpwm_halfbridge_task", 4096, NULL, 5, NULL);
    
    // Initialize WiFi first
    xTaskCreate(wifi_task, "wifi_task", 4096, NULL, 3, NULL);
    ESP_LOGI(TAG, "WiFi task started");
    
    // Start web server integration
    xTaskCreate(web_integration_task, "web_integration_task", 8192, NULL, 2, NULL);
    ESP_LOGI(TAG, "Web integration task started");
}

// In your stepper_task, you can now check for web commands:
void stepper_task(void *pvParameters)
{
    // ... existing initialization code ...
    
    while (1) {
        // Check for web interface commands
        if (get_jog_up_requested()) {
            // Execute jog up command
            ESP_LOGI(TAG, "Executing jog up from web interface");
            // Your jog up logic here
        }
        
        if (get_jog_down_requested()) {
            // Execute jog down command
            ESP_LOGI(TAG, "Executing jog down from web interface");
            // Your jog down logic here
        }
        
        if (get_home_position_requested()) {
            // Execute home position command
            ESP_LOGI(TAG, "Executing home position from web interface");
            // Your home position logic here
        }
        
        // Check if EDM cutting is enabled via web interface
        if (get_edm_cutting_status()) {
            // Your EDM cutting logic here
            // This replaces the manual start_cut button logic
        }
        
        // ... rest of your existing stepper task code ...
    }
}
*/ 

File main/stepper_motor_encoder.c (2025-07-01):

/*
 * SPDX-FileCopyrightText: 2021-2022 Espressif Systems (Shanghai) CO LTD
 *
 * SPDX-License-Identifier: Apache-2.0
 */

#include "esp_check.h"
#include "stepper_motor_encoder.h"

static const char *TAG = "stepper_motor_encoder";

static float convert_to_smooth_freq(uint32_t freq1, uint32_t freq2, uint32_t freqx)
{
    float normalize_x = ((float)(freqx - freq1)) / (freq2 - freq1);
    // third-order "smoothstep" function: https://en.wikipedia.org/wiki/Smoothstep
    float smooth_x = normalize_x * normalize_x * (3 - 2 * normalize_x);
    return smooth_x * (freq2 - freq1) + freq1;
}

typedef struct {
    rmt_encoder_t base;
    rmt_encoder_handle_t copy_encoder;
    uint32_t sample_points;
    struct {
        uint32_t is_accel_curve: 1;
    } flags;
    rmt_symbol_word_t curve_table[];
} rmt_stepper_curve_encoder_t;

static size_t rmt_encode_stepper_motor_curve(rmt_encoder_t *encoder, rmt_channel_handle_t channel, const void *primary_data, size_t data_size, rmt_encode_state_t *ret_state)
{
    rmt_stepper_curve_encoder_t *motor_encoder = __containerof(encoder, rmt_stepper_curve_encoder_t, base);
    rmt_encoder_handle_t copy_encoder = motor_encoder->copy_encoder;
    rmt_encode_state_t session_state = RMT_ENCODING_RESET;
    uint32_t points_num = *(uint32_t *)primary_data;
    size_t encoded_symbols = 0;
    if (motor_encoder->flags.is_accel_curve) {
        encoded_symbols = copy_encoder->encode(copy_encoder, channel, &motor_encoder->curve_table[0],
                                               points_num * sizeof(rmt_symbol_word_t), &session_state);
    } else {
        encoded_symbols = copy_encoder->encode(copy_encoder, channel, &motor_encoder->curve_table[0] + motor_encoder->sample_points - points_num,
                                               points_num * sizeof(rmt_symbol_word_t), &session_state);
    }
    *ret_state = session_state;
    return encoded_symbols;
}

static esp_err_t rmt_del_stepper_motor_curve_encoder(rmt_encoder_t *encoder)
{
    rmt_stepper_curve_encoder_t *motor_encoder = __containerof(encoder, rmt_stepper_curve_encoder_t, base);
    rmt_del_encoder(motor_encoder->copy_encoder);
    free(motor_encoder);
    return ESP_OK;
}

static esp_err_t rmt_reset_stepper_motor_curve_encoder(rmt_encoder_t *encoder)
{
    rmt_stepper_curve_encoder_t *motor_encoder = __containerof(encoder, rmt_stepper_curve_encoder_t, base);
    rmt_encoder_reset(motor_encoder->copy_encoder);
    return ESP_OK;
}

esp_err_t rmt_new_stepper_motor_curve_encoder(const stepper_motor_curve_encoder_config_t *config, rmt_encoder_handle_t *ret_encoder)
{
    esp_err_t ret = ESP_OK;
    rmt_stepper_curve_encoder_t *step_encoder = NULL;
    float smooth_freq;
    uint32_t symbol_duration;
    ESP_GOTO_ON_FALSE(config && ret_encoder, ESP_ERR_INVALID_ARG, err, TAG, "invalid arguments");
    ESP_GOTO_ON_FALSE(config->sample_points, ESP_ERR_INVALID_ARG, err, TAG, "sample points number can't be zero");
    ESP_GOTO_ON_FALSE(config->start_freq_hz != config->end_freq_hz, ESP_ERR_INVALID_ARG, err, TAG, "start freq can't equal to end freq");
    step_encoder = rmt_alloc_encoder_mem(sizeof(rmt_stepper_curve_encoder_t) + config->sample_points * sizeof(rmt_symbol_word_t));
    ESP_GOTO_ON_FALSE(step_encoder, ESP_ERR_NO_MEM, err, TAG, "no mem for stepper curve encoder");
    rmt_copy_encoder_config_t copy_encoder_config = {};
    ESP_GOTO_ON_ERROR(rmt_new_copy_encoder(&copy_encoder_config, &step_encoder->copy_encoder), err, TAG, "create copy encoder failed");
    bool is_accel_curve = config->start_freq_hz < config->end_freq_hz;
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

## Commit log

2025-06-09 proper ADC timing
2025-07-01 stepper works
2025-07-01 ADC and Queue working
2025-07-01 change the ADC to latest
2025-07-01 ADC works well
2025-07-01 change from ledc to pcpwm
2025-07-01 added sparc on pin
2025-07-01 control loop with ADC and spark on signal
2025-07-01 change tick rate on 1000hz
2025-07-01 added logic for buttons
2025-07-01 fixed ADC motor still crash
    [ADC.c, main.c]
2025-07-01 added yeld for limit switch
2025-07-01 nu mai crapa are ADC on gpio16 on
2025-07-01 hardware test stepper ok
2025-07-01 changed to s curve encoder
2025-07-01 corrected some bullshet from AI
    [main.c]
2025-07-01 removed PWM-ledc
2025-07-07 added schematic
2025-07-07 power train
    [power train2.kicad_pcb, power train2.kicad_sch]
2025-07-08 ADC adjust the duty cycle
2025-07-09 added PID values to web
2025-07-09 web interface is working better now and moust of t he button are functional now
2025-07-10 impruved stepper task speed control to 2 miliseconds
